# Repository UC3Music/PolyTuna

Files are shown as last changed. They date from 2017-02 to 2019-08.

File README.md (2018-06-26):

PolyTuna
-----

    This is a work in progress
    
A DIY polyphonic guitar tuner pedal. With it you can check the tuning of all the strings with a single strum, saving you time when you need it most. Very useful for playing live!

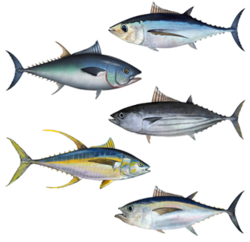
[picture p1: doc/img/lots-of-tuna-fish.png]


This work has been developed by [Sergio Sánchez](https://github.com/SerjSanchez) as his Bachelor's Thesis, with [David Estevez](https://github.com/David-Estevez) as his advisor. The Thesis itself can be downloaded [here](https://github.com/UC3Music/PolyTuna/raw/master/Memoria.pdf) (in Spanish).

The work has three main parts:

* A preeliminary study of the guitar signal to decide the best analysis technique for the pedal. This study was made in Matlab and the sources for the study can be found in the `MATLAB Analysis` folder.
* A software implementation of the polyphonic tuner to validate the algorithms prior to the hardware implementation. This code is written in Python and contained in the `Software tuner` folder.
* A hardware implementation (i.e. the pedal itself). The firmware for the device is stored in the `Polytuna Teensy Edition` folder. The schematics can be found in the [Thesis document](https://github.com/UC3Music/PolyTuna/raw/master/Memoria.pdf). The full circuit and the PCB KiCad project can be found at [`Polytuna KiCad`](https://github.com/UC3Music/PolyTuna/tree/master/Polytuna%20KiCad) folder.

Some pictures of the prototype:
(HD images can be found [`here`](https://github.com/UC3Music/PolyTuna/tree/master/doc/img/Polytuna%20PCB%20v1%20photos/HD))

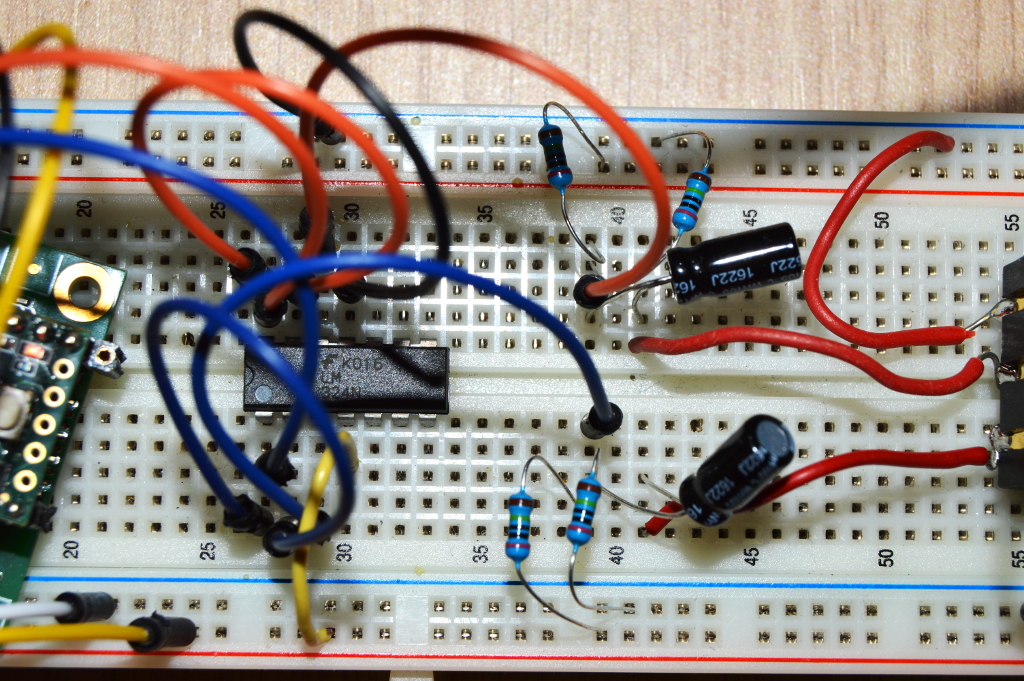
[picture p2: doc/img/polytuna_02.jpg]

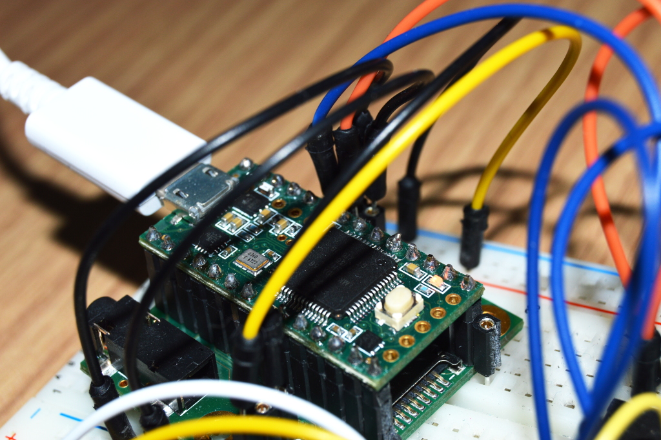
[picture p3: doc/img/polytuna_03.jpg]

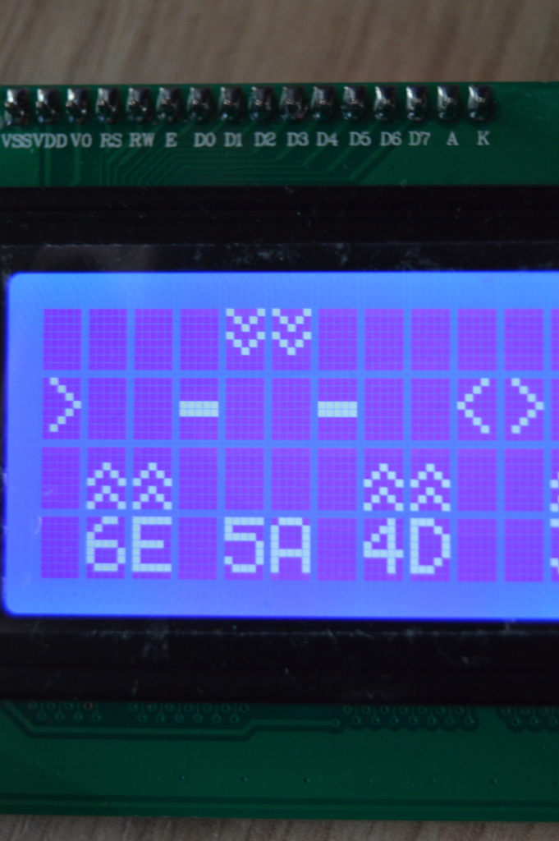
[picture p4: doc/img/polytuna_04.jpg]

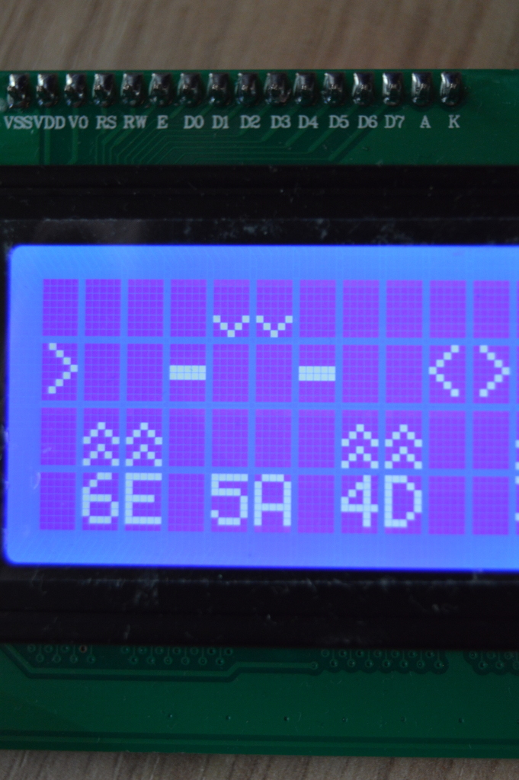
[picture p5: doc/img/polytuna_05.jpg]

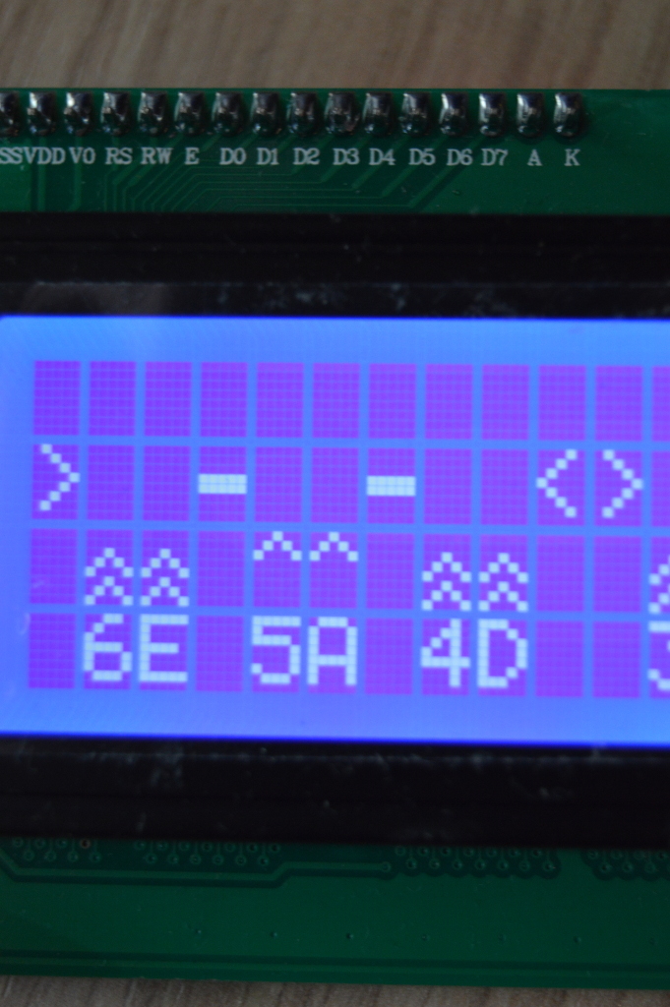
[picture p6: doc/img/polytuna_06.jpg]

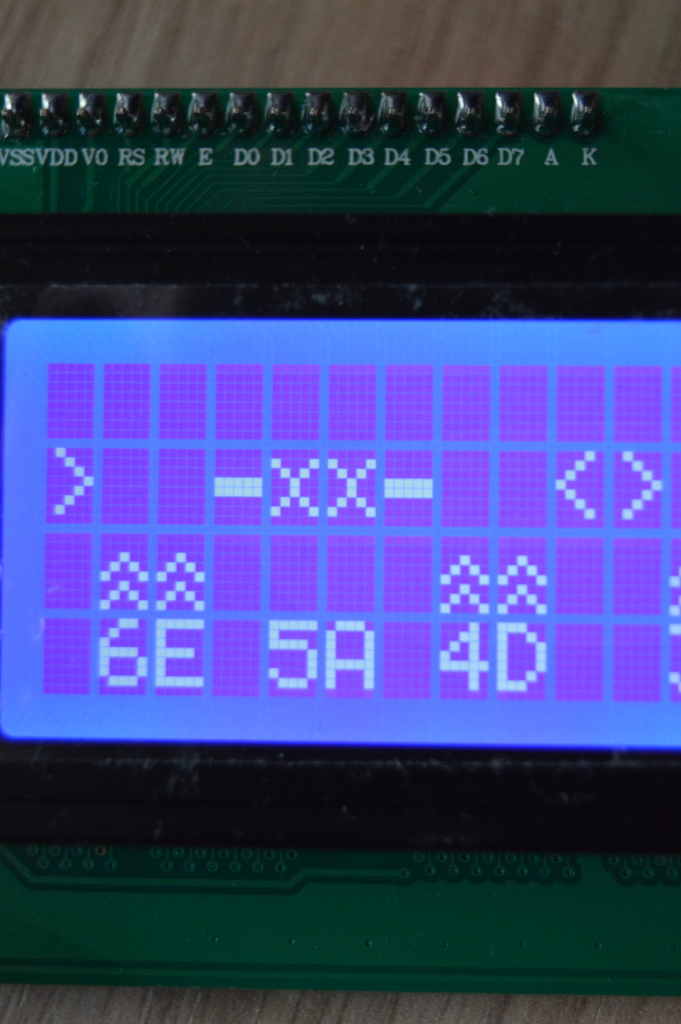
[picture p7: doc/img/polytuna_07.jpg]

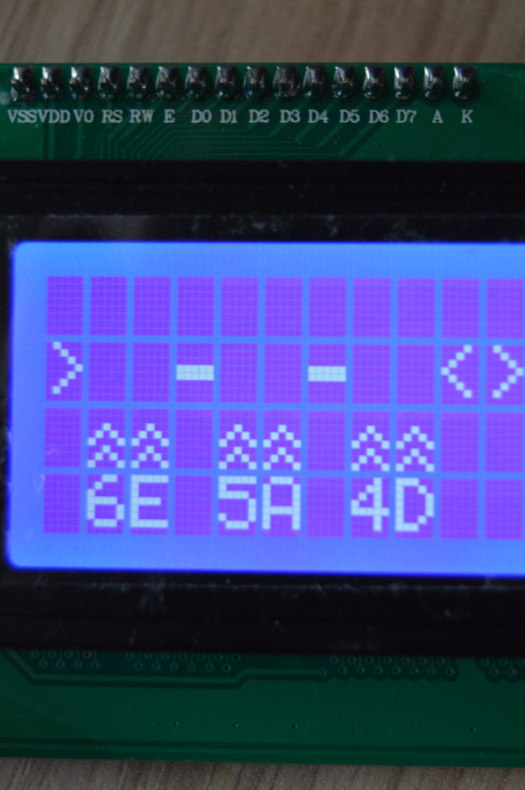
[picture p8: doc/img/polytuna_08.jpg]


The last completed step was the creation of a first PCB prototype, shown on the images, that's fully functional as a tuner.
Currently the work is focused on improving the display software capabilities to ensure it's easily readable.

#### Author
	
* Sergio Sánchez 

#### Advisor
    
*  [David Estévez Fernández](https://github.com/David-Estevez)

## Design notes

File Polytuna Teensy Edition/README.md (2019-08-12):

Hardware implementation of the Polytuna pedal. A simple version of the schematics can be found in the [Thesis document](https://github.com/UC3Music/PolyTuna/raw/master/Memoria.pdf) and the PCB-ready version can be found on the [PolyTuna KiCad folder](https://github.com/UC3Music/PolyTuna/tree/master/Polytuna%20KiCad)

This firmware requires both [Arduino](https://www.arduino.cc/) and the [Teensyduino add-on](https://www.pjrc.com/teensy/teensyduino.html).

In order to get Polytuna fully working in Teensy, some stock libraries need to be modified. These changes ensure the sampling frequency is 8kHz instead of the 44.1kHz standard in Teensy to get a more precise FFT.

    **TO AVOID FUTURE PROBLEMS, SAVE THE ORIGINAL FILES BEFORE OVERWRITING ANYTHING.**
	
* `AudioStream.h`. Overwrite the following file: `(Arduino installation folder)/Arduino/hardware/teensy/avr/cores/teensy3/AudioStream.h` (with '\' instead of '/' on Windows-based systems).
			
* `output_i2s.cpp`. Overwrite the following file: `(Arduino installation folder)/Arduino/hardware/teensy/avr/libraries/Audio/output_i2s.cpp` (with '\' instead of '/' on Windows-based systems).

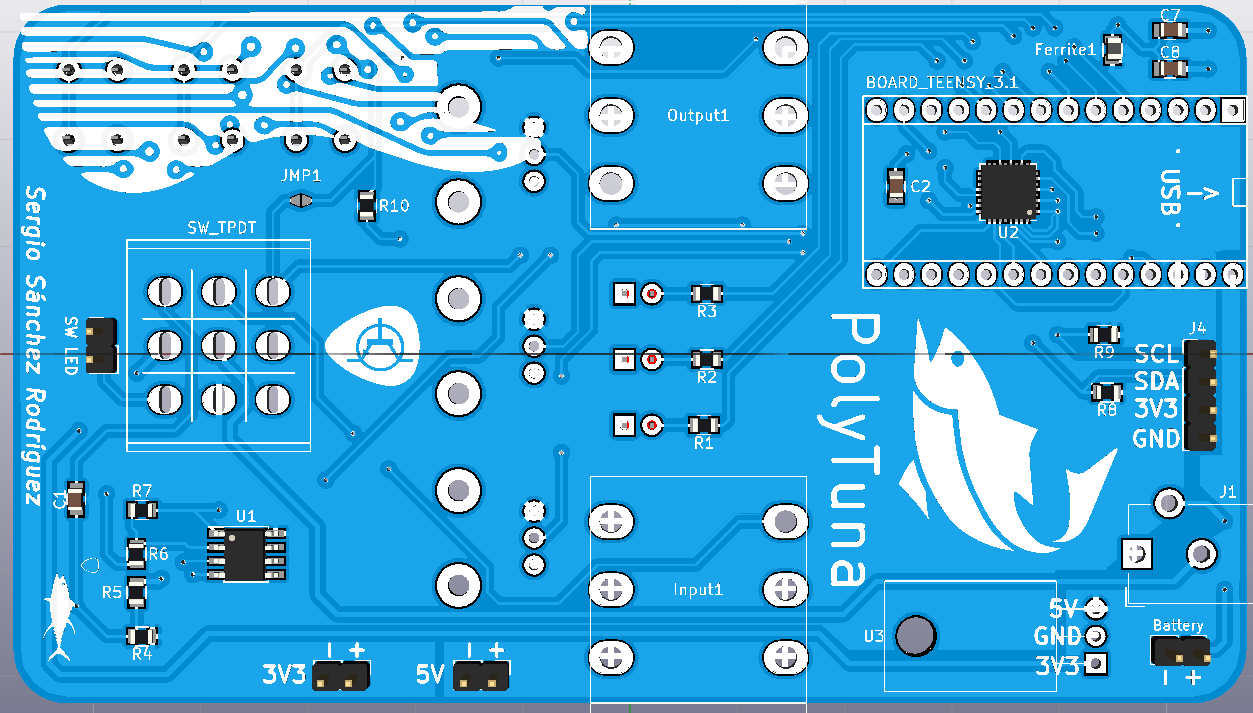
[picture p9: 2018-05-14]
doc/img/PCB 3D Render/Polytuna_front.PNG

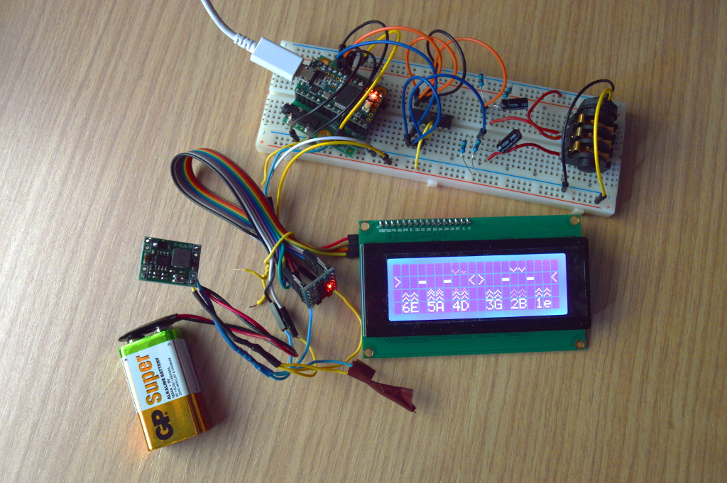
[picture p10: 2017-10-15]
doc/img/Protoboard prototype/polytuna.jpg

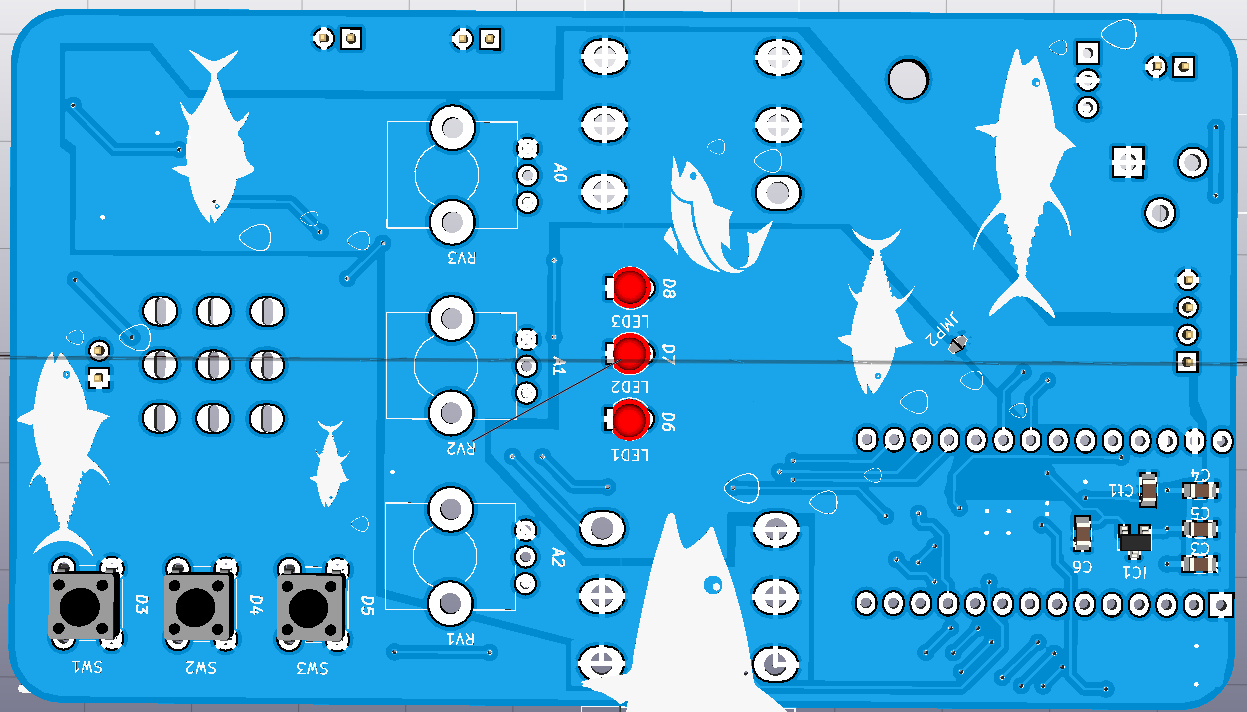
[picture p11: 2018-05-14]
doc/img/PCB 3D Render/Polytuna_back.PNG

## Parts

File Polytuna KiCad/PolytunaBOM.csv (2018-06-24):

Id | Identificador | Empaquetado | Cantidad | Identificación | Suministrador y ref
1 | G***,G***,G***,G***,G***,G***,G***,G*** | pick_contour_1.7mm | 8 | LOGO
2 | G*** | tuna_fish_back1_L_54.2x27.1mm | 1 | LOGO
3 | G*** | tuna_fish_back3_L_19x9.5mm | 1 | LOGO
4 | BOARD1 | Board_Teensy_3_1 | 1 | BOARD_TEENSY_3.1
5 | BT1 | Pin_Header_Straight_1x02_Pitch2.54mm | 1 | Battery
6 | C1 | C_0805 | 1 | C
7 | C2,C3,C6,C8 | C_0805 | 4 | 2.2uF
8 | C4,C5,C7 | C_0805 | 3 | 0.1uF
9 | Ct1 | C_0805 | 1 | 0.15uF
10 | Ferrite1 | L_0805 | 1 | 600
11 | IC1 | SOT-23 | 1 | AP7313-33SAG-7
12 | J1 | Barrel_Jack_CUI_PJ-102AH | 1 | Barrel_Jack
13 | JMP1,JMP2 | Miscellaneous_Solder_Jumper | 2 | 2Jumper
14 | R1,R2,R3,R4,R5,R6,R7 | R_0805 | 7 | R
15 | R8,R9 | R_0805 | 2 | 2.2K
16 | R10 | R_0805 | 1 | 10M
17 | RV1,RV2,RV3 | Potentiometer_Alps_RK09K_Horizontal | 3 | POT_TRIM
18 | SW1,SW2,SW3 | SW_PUSH_6mm_h5mm | 3 | SW_Push
19 | U2 | QFN-32-1EP_5x5mm_Pitch0.5mm | 1 | SGTL5000
20 | U3 | TO-220-3_Horizontal | 1 | L7805
21 | Input1,Output1 | CONN_Jack_Female_6.35mm_THD | 2 | JACK_FEMALE_STEREO_6_PINS
22 | SW4 | IceStomp_Switch_3PDT | 1 | SW_TPDT
23 | J2,J3,J5 | Pin_Header_Straight_1x02_Pitch2.54mm | 3 | Conn_01x02
24 | J4 | Pin_Header_Straight_1x04_Pitch2.54mm | 1 | Conn_01x04
25 | G*** | logo_guitar_52.6.5x18.4mm | 1 | LOGO
26 | G*** | logo_pick_10x10mm | 1 | LOGO
27 | G*** | tuna_fish_logo_21.7x21.7mm | 1 | LOGO
28 | G*** | tuna_fish_back1_L_25x12.5mm | 1 | LOGO
29 | G*** | tuna_fish_back2_R_16.4x16.4mm | 1 | LOGO
30 | G*** | tuna_fish_back3_R_15.5x7.7mm | 1 | LOGO
31 | G*** | tuna_fish_back1_L_8.1x4.1mm | 1 | LOGO
32 | G*** | tuna_fish_back3_R_8.1x8.1mm | 1 | LOGO
33 | G*** | tuna_fish_logo_10.8x10.8mm | 1 | LOGO
34 | G***,G*** | pick_contour_3mm | 2 | LOGO
35 | G***,G*** | pick_contour_3.4mm | 2 | LOGO
36 | G***,G***,G*** | pick_contour_2.7mm | 3 | LOGO
37 | G***,G*** | pick_contour_2.2mm | 2 | LOGO
38 | U1 | SOIC-8_3.9x4.9mm_Pitch1.27mm | 1 | LM358
39 | LED1,LED2,LED3 | LED_D3.0mm | 3 | LED

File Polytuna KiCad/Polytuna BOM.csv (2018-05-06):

Reference | Component | Amount | Reference | Seller | Unit Cost | Cost
Input1;Output1 | Jack Female 6.35mm THD | 2 | 568-NYS219 | Mouser | 0.724 | 1.448
LED1-LED3 | LED Diode 3mm THD | 3 |  | Mouser |  | 0
R1-R3 | Resistor 0805 100R | 3 |  |  |  | 0
R4;R10 | Resistor 0805 10M | 2 |  |  |  | 0
R5 | Resistor 0805 2M | 1 |  | Mouser |  | 0
R6 | Resistor 0805 10K | 1 |  |  |  | 0
R7 | Resistor 0805 20K | 1 |  |  |  | 0
R8-R9 | Resistor 0805 2K2 | 2 |  | Mouser |  | 0
RV1-RV3 | Potentiometer ALPS RK09K ? | 3 |  |  |  | 0
U1 | Op-Amp LM358 | 1 |  |  |  | 0
U2 | Audio Codec SGTL5000 (QFN32EP) | 1
U3 | DC/DC Converter VXO7805-500 | 1 | 490-VXO7805-500
J1 | Barrel jack PJ-102AH | 1 | 490-PJ-102AH | Mouser | 0.615 | 0.615
C1 | Capacitor 0805 ceramic 10uF | 1 |  |  |  | 0
C2-C3;C6;C8 | Capacitor 0805 ceramic 2.2uF | 4 |  | Mouser |  | 0
C4;C5;C7 | Capacitor 0805 ceramic 0.1uF | 3 |  | Mouser |  | 0
Ct1 | Capacitor 0805 ceramic 0.15uF | 1 |  | Mouser |  | 0
Ferrite1 | Ferrite bead 0805 600ohms | 1
SW1-SW3 | Switch 6x5mm | 3 |  | Mouser |  | 0
SW4 | Switch 3PDT | 1 |  | Aliexpress
IC1 | Regulator AP7313-33SAG-7 | 1
BOARD1 | Teensy 3.1 | 1 | - | - |  | 0
 |  |  |  |  | Total: | 2.063

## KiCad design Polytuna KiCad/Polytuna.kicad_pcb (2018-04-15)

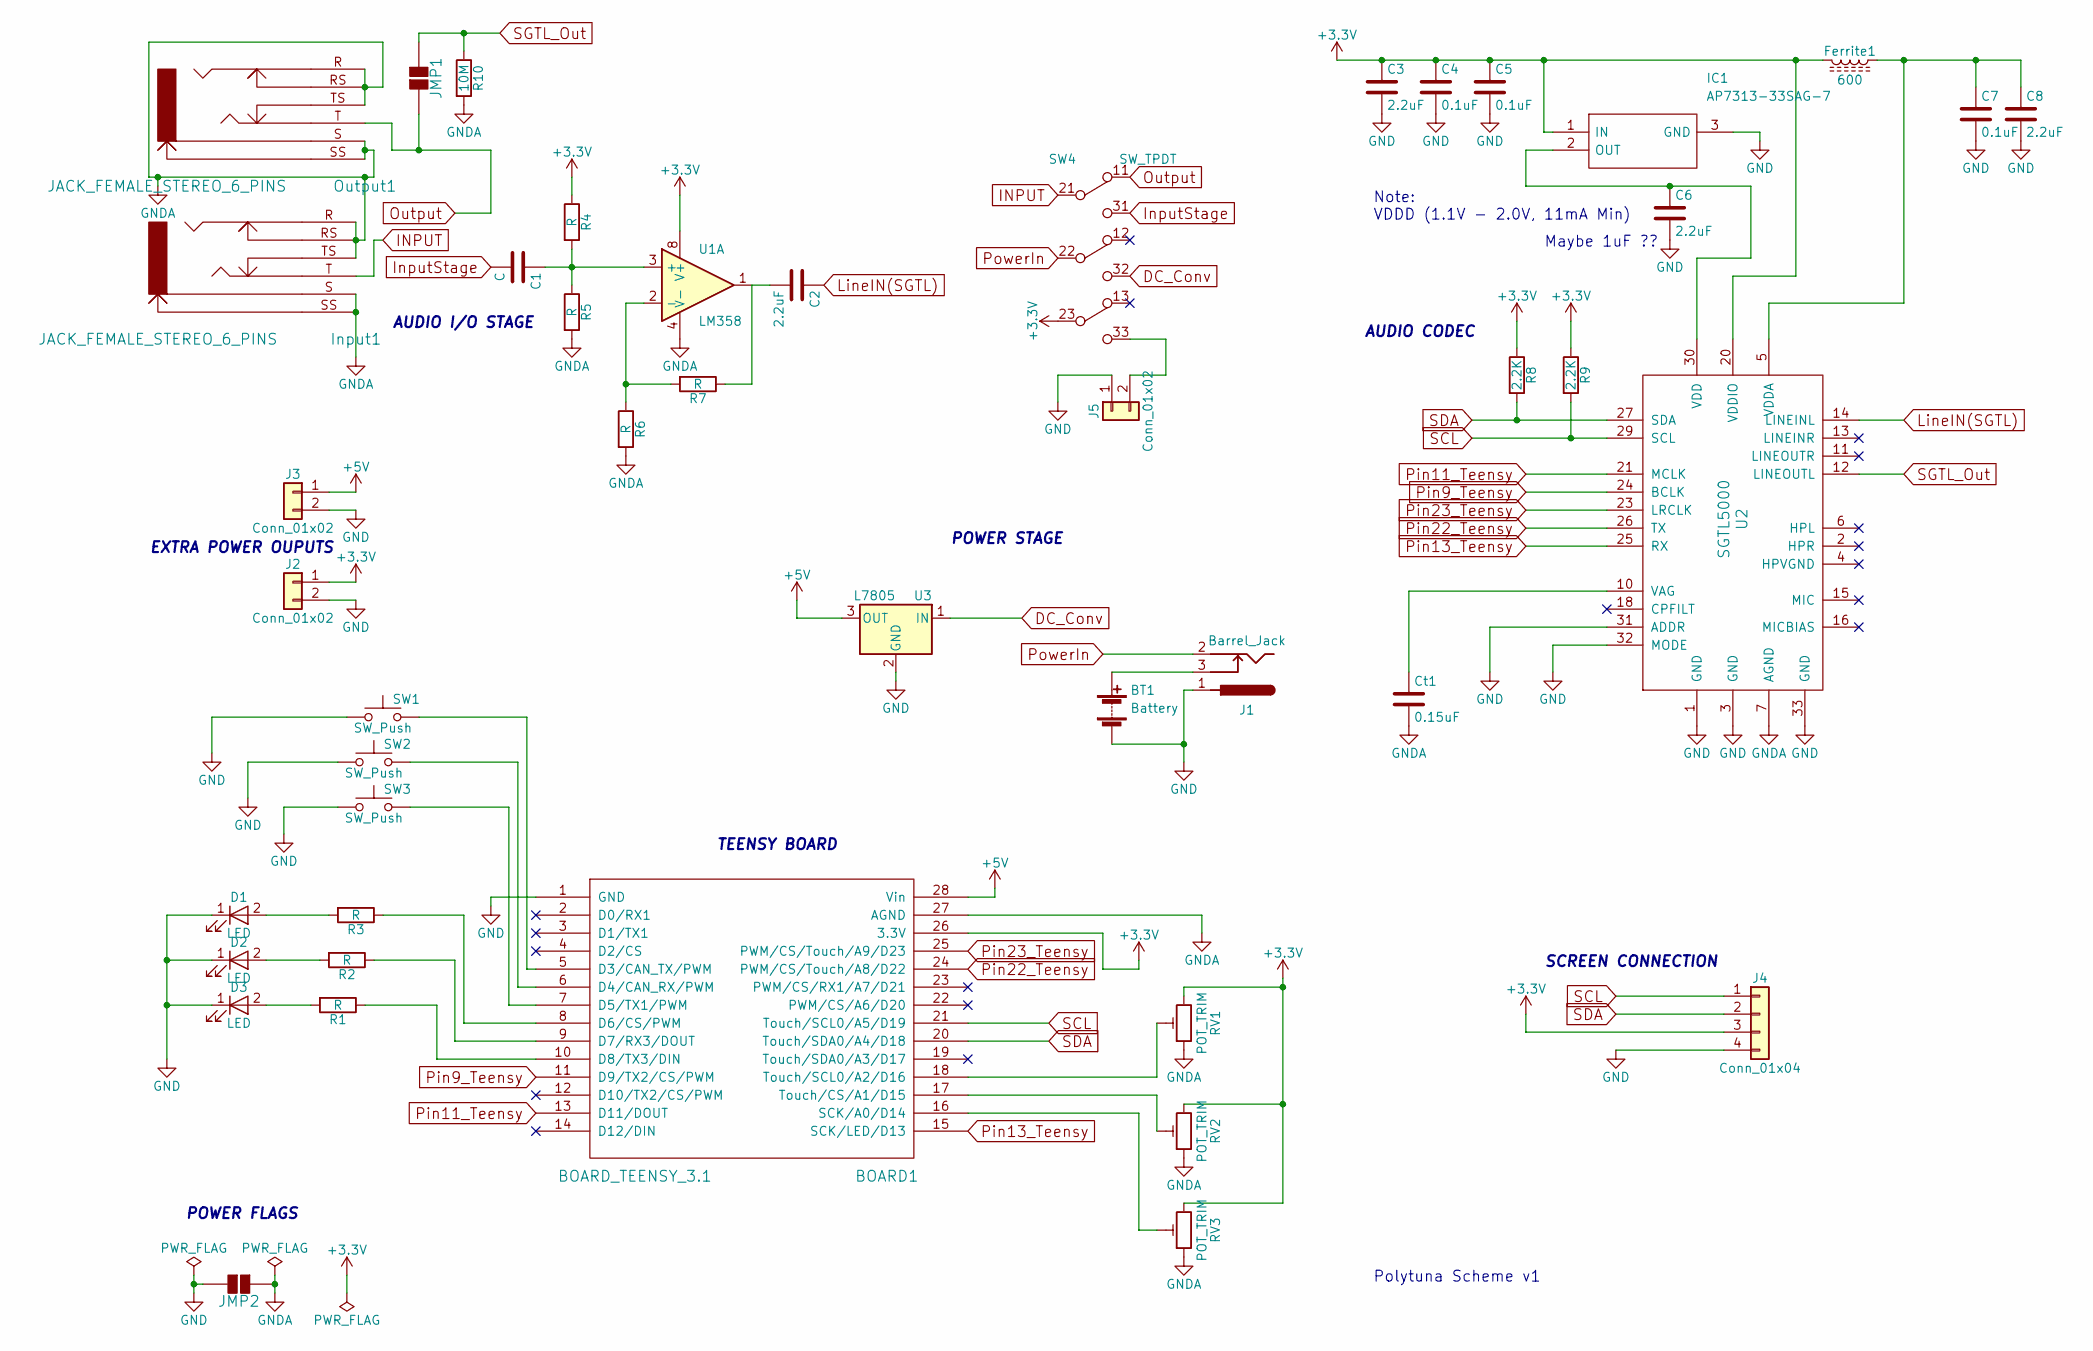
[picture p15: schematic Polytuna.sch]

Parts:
BOARD1: BOARD_TEENSY_3.1; Board_Teensy_3_1
BT1: Battery; Pin_Header_Straight_1x02_Pitch2.54mm
C1: C; C_0805
C2, C3, C6, C8: 2.2uF; C_0805
C4, C5, C7: 0.1uF; C_0805
Ct1: 0.15uF; C_0805
D1, D2, D3: LED; LED_D3.0mm
Ferrite1: 600; L_0805
IC1: AP7313-33SAG-7; SOT-23; Manufacturer_Part_Number AP7313-33SAG-7
Input1: JACK_FEMALE_STEREO_6_PINS; CONN_Jack_Female_6.35mm_THD
J1: Barrel_Jack; Barrel_Jack_CUI_PJ-102AH
J2, J3, J5: Conn_01x02; Pin_Header_Straight_1x02_Pitch2.54mm
J4: Conn_01x04; Pin_Header_Straight_1x04_Pitch2.54mm
JMP1, JMP2: 2Jumper; Miscellaneous_Solder_Jumper
Output1: JACK_FEMALE_STEREO_6_PINS; CONN_Jack_Female_6.35mm_THD
R1, R2, R3, R4, R5, R6, R7: R; R_0805
R8, R9: 2.2K; R_0805
R10: 10M; R_0805
RV1, RV2, RV3: POT_TRIM; Potentiometer_Alps_RK09K_Horizontal
SW1, SW2, SW3: SW_Push; SW_PUSH_6mm_h5mm
SW4: SW_TPDT; IceStomp_Switch_3PDT
U1: LM358; SOIC-8_3.9x4.9mm_Pitch1.27mm
U2: SGTL5000; QFN-32-1EP_5x5mm_Pitch0.5mm
U3: L7805; TO-220-3_Horizontal

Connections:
+3V3: BOARD1.26 (3.3V), C3.1, C4.1, C5.1, Ferrite1.2, IC1.1 (IN), J2.1, J4.3, R4.1, R8.1, R9.1, RV1.3, RV2.3, RV3.3, SW4.23, U1.8 (V+), U2.20 (VDDIO)
+5V: BOARD1.28 (Vin), J3.1, U3.3 (OUT)
DC_Conv: SW4.32, U3.1 (IN)
GND: BOARD1.1 (GND), BT1.2 (-), C3.2, C4.2, C5.2, C6.2, C7.2, C8.2, D1.1 (K), D2.1 (K), D3.1 (K), IC1.3 (GND), J1.1, J2.2, J3.2, J4.4, J5.1, JMP2.2, SW1.1, SW2.1, SW3.1, U2.1 (GND), U2.3 (GND), U2.31 (ADDR), U2.32 (MODE), U2.33 (GND), U3.2 (GND); also elsewhere on the board
GNDA: BOARD1.27 (AGND), Ct1.2, Input1.R, Input1.RS, Input1.S, Input1.SS, Input1.TS, JMP2.1, Output1.R, Output1.RS, Output1.S, Output1.SS, Output1.TS, R5.2, R6.2, R10.2, RV1.1, RV2.1, RV3.1, U1.4 (V-), U2.7 (AGND)
INPUT: Input1.T, SW4.21
InputStage: C1.2, SW4.31
LineIN(SGTL): C2.1, U2.14 (LINEINL)
unnamed: BOARD1.5 (D3/CAN_TX/PWM), SW1.2
unnamed: BOARD1.6 (D4/CAN_RX/PWM), SW2.2
unnamed: BOARD1.7 (D5/TX1/PWM), SW3.2
unnamed: BOARD1.8 (D6/CS/PWM), R3.1
unnamed: BOARD1.9 (D7/RX3/DOUT), R2.1
unnamed: BOARD1.10 (D8/TX3/DIN), R1.1
unnamed: BOARD1.16 (SCK/A0/D14), RV3.2
unnamed: BOARD1.17 (Touch/CS/A1/D15), RV2.2
unnamed: BOARD1.18 (Touch/SCL0/A2/D16), RV1.2
unnamed: BT1.1 (+), J1.3
unnamed: C1.1, R4.2, R5.1, U1.3 (+)
unnamed: C2.2, R7.1, U1.1
unnamed: C6.1, IC1.2 (OUT), U2.30 (VDD)
unnamed: C7.1, C8.1, Ferrite1.1, U2.5 (VDDA)
unnamed: Ct1.1, U2.10 (VAG)
unnamed 31: D1.2 (A), R3.2; also elsewhere on the board
unnamed 32: D2.2 (A), R2.2; also elsewhere on the board
unnamed 33: D3.2 (A), R1.2; also elsewhere on the board
unnamed: J5.2, SW4.33
unnamed: R6.1, R7.2, U1.2 (-)
Output: JMP1.2, Output1.T, SW4.11
Pin9_Teensy: BOARD1.11 (D9/TX2/CS/PWM), U2.24 (BCLK)
Pin11_Teensy: BOARD1.13 (D11/DOUT), U2.21 (MCLK)
Pin13_Teensy: BOARD1.15 (SCK/LED/D13), U2.25 (RX)
Pin22_Teensy: BOARD1.24 (PWM/CS/Touch/A8/D22), U2.26 (TX)
Pin23_Teensy: BOARD1.25 (PWM/CS/Touch/A9/D23), U2.23 (LRCLK)
PowerIn: J1.2, SW4.22
SCL: BOARD1.21 (Touch/SCL0/A5/D19), J4.1, R9.2, U2.29 (SCL)
SDA: BOARD1.20 (Touch/SDA0/A4/D18), J4.2, R8.2, U2.27 (SDA)
SGTL_Out: JMP1.1, R10.1, U2.12 (LINEOUTL)

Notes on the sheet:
Polytuna Scheme v1
TEENSY BOARD
AUDIO CODEC
POWER STAGE
AUDIO I/O STAGE
POWER FLAGS
SCREEN CONNECTION
Note: VDDD (1.1V - 2.0V, 11mA Min)
EXTRA POWER OUPUTS
Maybe 1uF ??

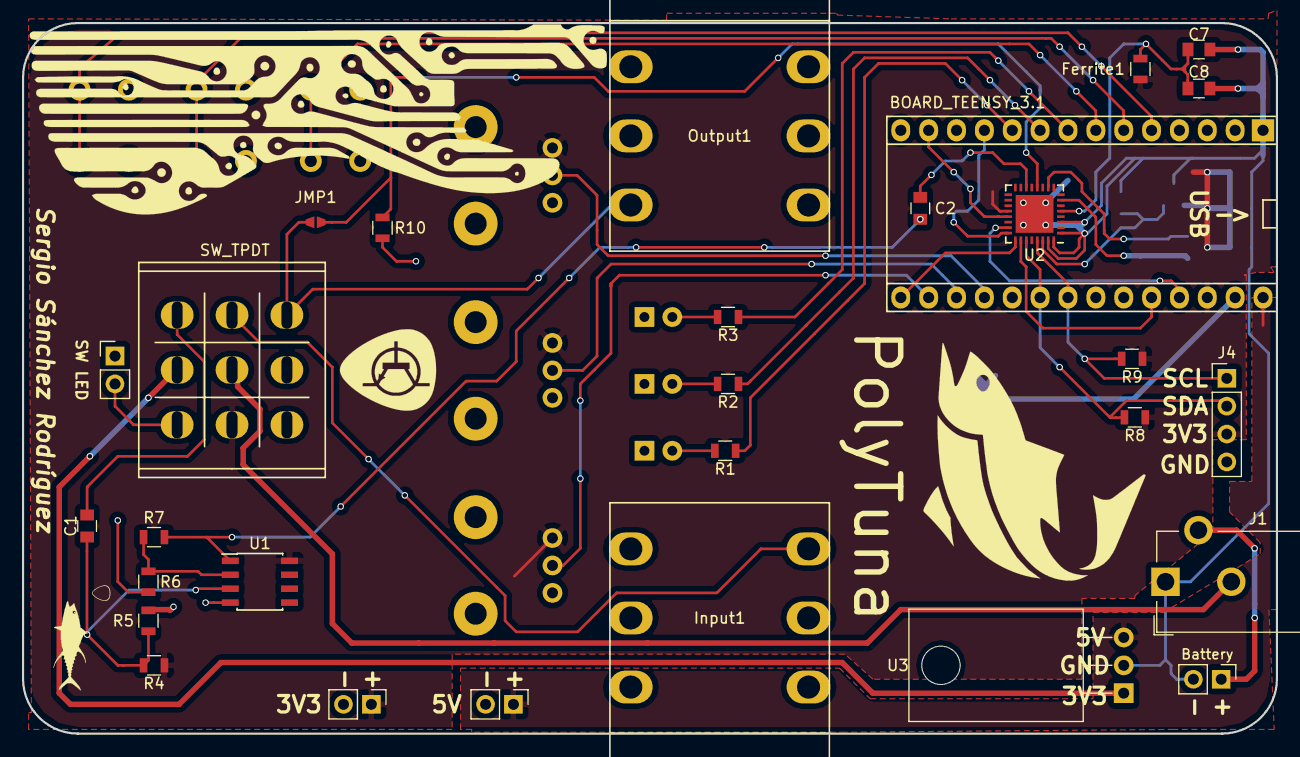
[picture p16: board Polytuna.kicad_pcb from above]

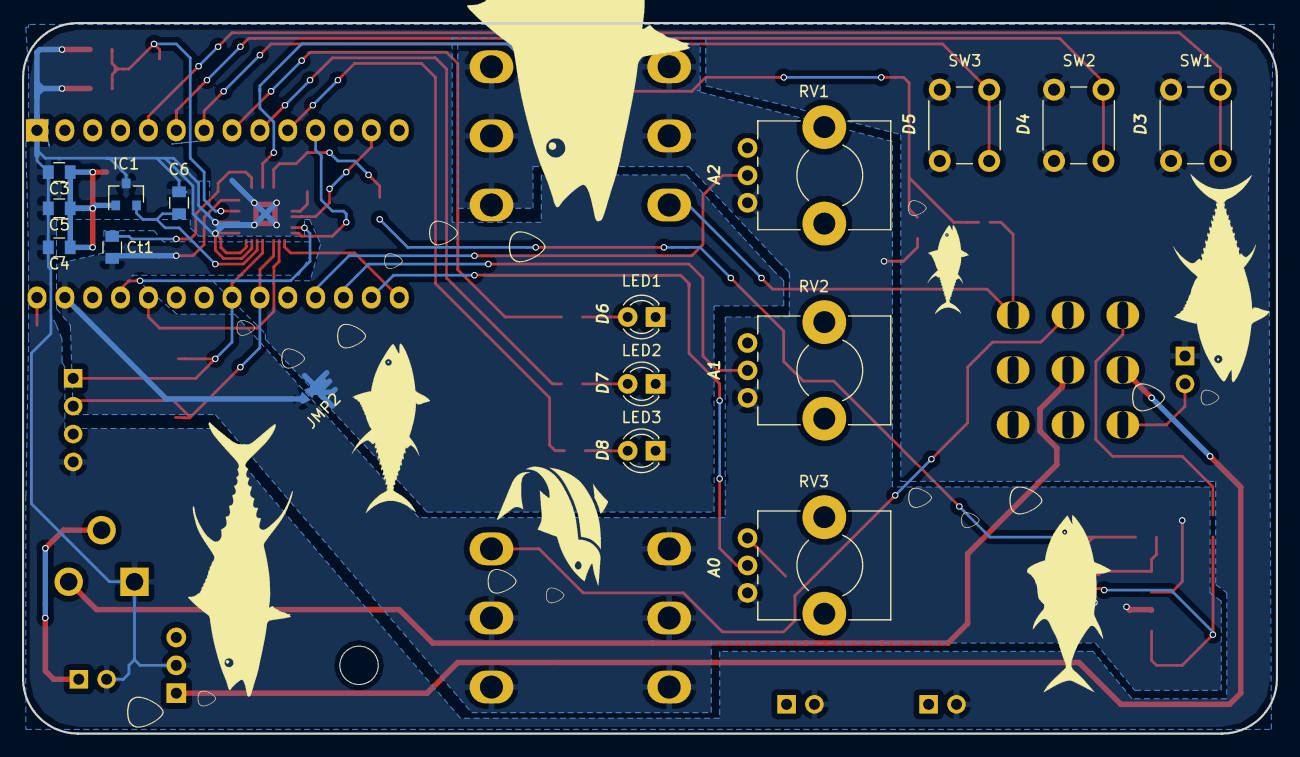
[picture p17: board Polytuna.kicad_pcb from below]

Board: 2 copper layers, 114.3 x 64.8 mm, 45 parts (16 on the bottom side), 38 nets.

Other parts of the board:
LED1, LED2, LED3: LED; LED_D3.0mm

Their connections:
GND: LED1.1, LED2.1, LED3.1; also elsewhere on the board
unnamed 31: LED1.2; also elsewhere on the board
unnamed 32: LED2.2; also elsewhere on the board
unnamed 33: LED3.2; also elsewhere on the board

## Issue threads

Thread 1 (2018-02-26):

Design PCB

David-Estevez, 2018-02-26:
Steps:

* [x] Design schematic in Kicad
  * [x] Add old design
  * [x] Make required modifications
  * [x] Check new input stage
  * [x] Add DC-DC Conversor
  * [x] Check Teensy Board Connections
  * [x] Add AP7313
  * [x] Add 3 buttons to implement weird things
  * [x] Add 3 pots to implement weird things
  * [x] Add a jack output from SGTL5000 to implement weird things
  * [x] Add some LEDs to know when the weird things are ON/OFF
  * [x] Add SDA/SCL ports for the display
  * [x] Add some 3.3V and 5V extra ports
* [x] Select components / footprints
* [x] Design PCB
* [x] Double-check PCB
* [x] Triple-check PCB
* [x] Manufacture PCB

SerjSanchez, 2018-03-03:
* [ ] Drummer with metronome.

JorFru, 2018-03-04:
- [ ] Double check jack footprint on the good side of PCB.
- [ ] Double check if any component can block a connector, wire, etc.

SerjSanchez, 2018-04-16:
On production!!!

Closed 2018-04-16.

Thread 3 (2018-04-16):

BOM

SerjSanchez, 2018-04-16:
* [x] Decide input stage values for resistors
* [x] Buy components

David-Estevez, 2018-05-06:
Added BOM with required components (c6ac7de45cbd0cc7031ab835b28889445f510f84). Prices and references will be updated with final values when components have been bought.

David-Estevez, 2018-05-11:
I already bought the components and they have just arrived. Should I close this one?

SerjSanchez, 2018-05-11:
Yup

Closed 2018-05-11.

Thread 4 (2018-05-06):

PCB v2

SerjSanchez, 2018-05-06:
Some modifications for future versions of the PCB:

*[ ] Add regulation capacitors for the DC/DC converter.
*[ ] Remake PCB to achieve less than 10cm length.
** [ ] Remove components for the development board.
** [ ] Check that the battery actually fits in the box along with the PCB.

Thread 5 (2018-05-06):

Build prototype

SerjSanchez, 2018-05-06:
* [x] Solder SGTL5000 @David-Estevez
* [x] Solder all the available components
* [x] Test working on finished prototypes
* [ ] FInish the half done prototype
* [ ] Buy Teensys and voltage regulator caps
* [ ] Buy some LCDs
* [ ] Solder the missing components on all of the prototypes
* [ ] Test working on all the prototypes.

David-Estevez, 2018-05-11:
I have just received the required components that I ordered from Mouser. Let's schedule one day to go to the electronics lab in our uni and solder the SGTL5000 (unless @SerjSanchez is not interested in being present while I solder that).

L4g0, 2018-09-20:
Isn't this already done? Should we change this to the "Done" column in the projects tab?

SerjSanchez, 2018-09-21:
Actually, it's almost done. There are a few caps I forgot to include in the schematic that need to be "ñaped". Also, there is a prototype that has only half of the components cause we were not expecting to be able to build all of them the same day and we bought less from some of the components.

Also, there's only a prototype with a Teensy...

Anyway, would be nice to update this, so thanks for the reminder! ;)

Closed 2025-05-20.

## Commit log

2017-03-26 6 strings printed in one line. Corrected some comparation limits.
2017-04-07 Lagrange interpolation and better terminal printing
2017-08-27 Add files via upload
    Added Teensy implementation for Polytuna and the libraries to make it work. Only displays in serial. Needed to change the detection window for strings 1 & 2
2017-09-08 Comentarios mejorados y añadido el archivo mono_tuner.py
2017-09-10 Calibrated Poly tuner
2017-09-16 Calibrated and slightly better display
2018-03-02 First KiCad Schematic
    Needs a DC-DC conversor, AP7313, check Teensy board connections
    [Polytuna.kicad_pcb, Polytuna.sch]
2018-03-03 Added some switches, LEDs and jumpers
    [Polytuna.sch]
2018-03-03 Add switches, LEDs and jumpers
    [Polytuna.sch]
2018-03-07 Added some pwr_flags, AP7313
    [Polytuna.sch]
2018-03-08 Added i2c ports to scheme and power stage
    [Polytuna.sch]
2018-03-08 Solve power flag issues
    [Polytuna.sch]
2018-03-09 Corrected GNDA/GND and i2c pins
    [Polytuna.sch]
2018-03-09 Finished schematic
    [Polytuna.sch]
2018-03-09 Added some footprints
    [Polytuna.sch]
2018-03-12 footprint-component relation finished
    [Polytuna.kicad_pcb, Polytuna.sch]
2018-03-14 Started PCB
    [Polytuna.kicad_pcb]
2018-03-16 Progress in routing
    [Polytuna.kicad_pcb, Polytuna.sch]
2018-03-16 Moar routing
    [Polytuna.kicad_pcb, Polytuna.sch]
2018-03-17 Moar routing x2
    Still have to add the 3pdt
    [Polytuna.kicad_pcb, _saved_Polytuna.sch]
2018-03-17 PCB v0.1
    [Polytuna.kicad_pcb, Polytuna.sch, _saved_Polytuna.sch]
2018-03-23 Added some logos and changed silks
    [Polytuna.kicad_pcb]
2018-03-24 PCB v1
    PCB
    [Polytuna.sch]
2018-03-24 PCB v1
    [Polytuna.kicad_pcb, Polytuna.sch]
2018-03-28 Added some logos
    Still in need of tunas
    [Polytuna.kicad_pcb]
2018-03-28 Moar logos
    [Polytuna.kicad_pcb]
2018-03-30 Changed some logos. Added a tuna
    [Polytuna.kicad_pcb]
2018-03-30 MOAR TUNAS FOR EVERYBODY
    [Polytuna.kicad_pcb]
2018-04-01 Added some "Pibbles" and no DRC errors
    [Polytuna.kicad_pcb]
2018-04-02 PCB v1 finished
    [Polytuna.kicad_pcb]
2018-04-11 Some fixes
    [Polytuna.kicad_pcb, Polytuna.sch]
2018-04-11 Add GERGERs
    [Polytuna-B.Cu.gbl, Polytuna-B.Mask.gbs, Polytuna-B.SilkS.gbo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]
2018-04-11 Nice and round edges
    [Polytuna.kicad_pcb]
2018-04-12 Changed OP's footprint
    [Polytuna.kicad_pcb, Polytuna.sch]
2018-04-15 Regenerate GERBERs
    [Polytuna-B.Cu.gbl, Polytuna-B.Mask.gbs, Polytuna-B.Paste.gbp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]
2018-05-06 Added values for input stage resistors
    [Polytuna.sch]
2018-05-06 Add BOM
    [Polytuna BOM.csv]
2018-05-07 Corrected C6 value
    [Polytuna.sch]
2018-05-14 DC-DC conversor Datasheet and PCB 3D render
2018-06-24 Some PCB V1 photos
    Everything worked nice!
    [PolytunaBOM.csv]
2018-06-25 Update README.md
    Change the old prototype images to show the new one with the PCB
2018-06-25 Update README.md
    Added images of the new prototype with the PCB
